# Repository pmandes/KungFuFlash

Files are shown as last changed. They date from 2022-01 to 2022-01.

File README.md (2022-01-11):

# Kung Fu Flash - Long PCB version

This version of the cartridge was developed for the following purposes:
- to fit into standard housings matching PCBs in format and size of the EasyFlash 3 cartridge
- to make SMD manual soldering easier
- to prevent the leverage effect when pressing the buttons from above, which stressed the cartridge connector and caused the C64 to crash.

The original design can be found [here](https://github.com/KimJorgensen/KungFuFlash).

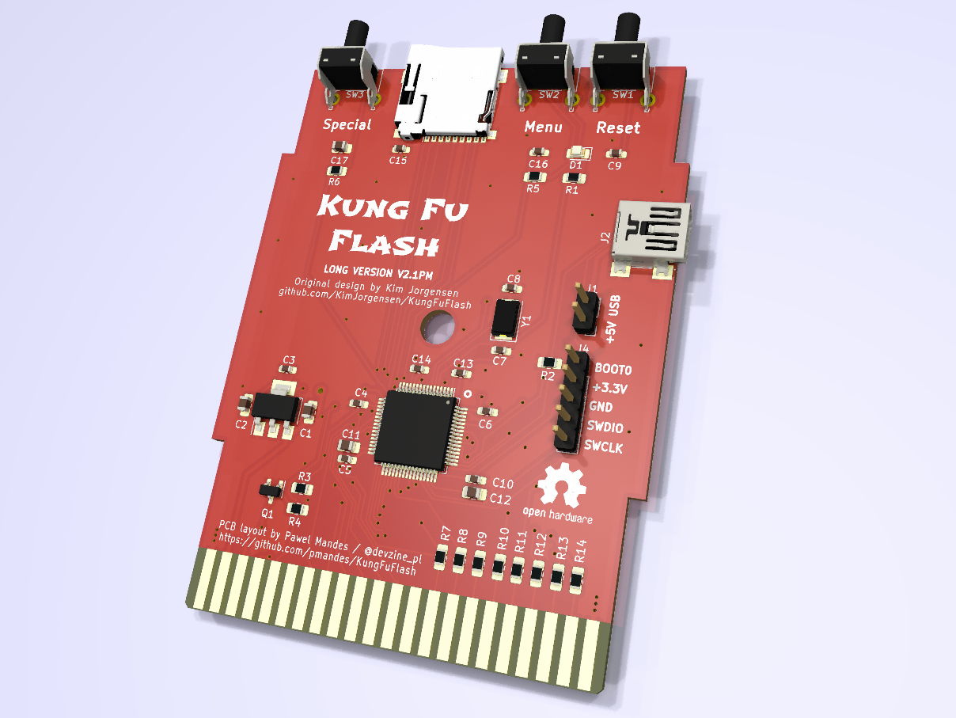
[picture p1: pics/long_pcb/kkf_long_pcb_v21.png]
KKF long board


Main changes:
- project migrated to KiCad 6.0
- 3D models for all components
- long PCB to fit common housings
- right angle tactile switches
- more durable Mini USB B socket for data transfer (you can use the same cable as EF3)
- 100Ω 0805 resistors for easier manual soldering (instead of resitor arrays)

The gerber files:
[KungFuFlash-Long-v2.1-PM.zip](https://github.com/pmandes/KungFuFlash/blob/long-board-cart/hardware/gerber/KungFuFlash-Long-v2.1-PM.zip)

Compatible housings:
- [KM-20B](https://www.tme.eu/en/details/km-20b/multipurpose-enclosures/maszczyk/)
- [Z7](https://www.kradex.eu/product/enclosures_two_part/z7_ps?lang=en)
- [Thingiverse](https://www.thingiverse.com/thing:1702546)
- "Commodore" type and others that EF3 fits

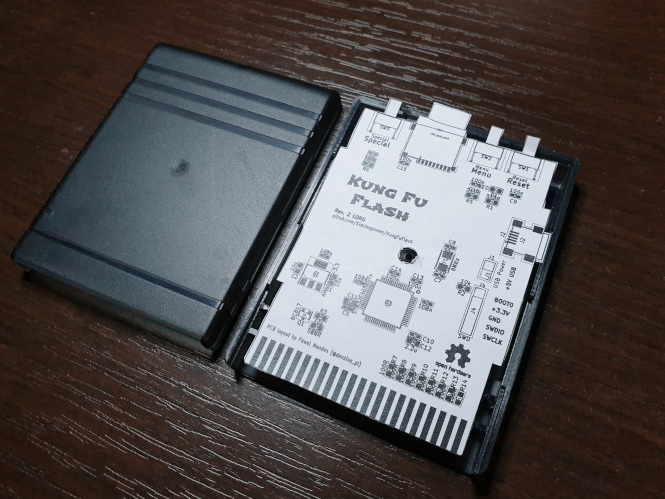
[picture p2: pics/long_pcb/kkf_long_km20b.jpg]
KKF KM-20B

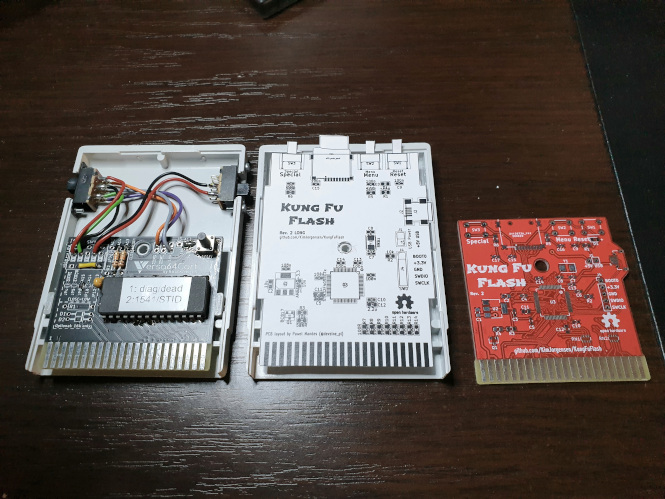
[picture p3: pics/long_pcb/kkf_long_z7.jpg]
KKF Z7

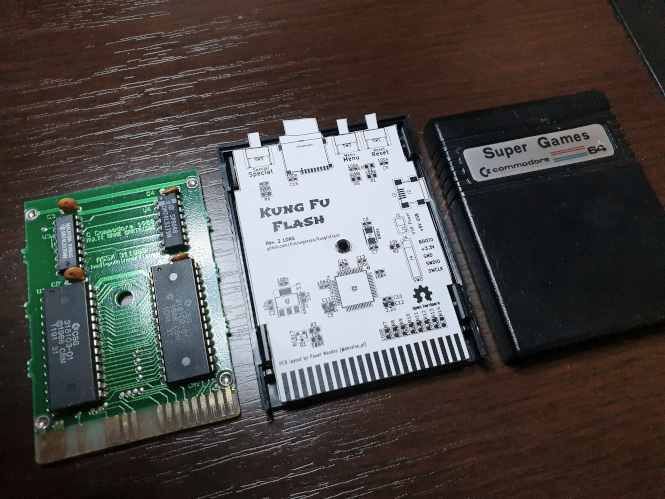
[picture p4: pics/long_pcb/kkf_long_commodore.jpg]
KKF Commodore Cart


# Kung Fu Flash
Cartridge for the Commodore 64 that packs a punch.

Kung Fu Flash Launcher

Kung Fu Flash can emulate different cartridge types, load PRG files and use D64 disk images.
Just place your desired CRT, PRG or D64 files on a FAT formatted microSD card and use the built-in launcher to execute them.

## Hardware
There are three buttons on the cartridge; a reset button, a menu button for starting the launcher, and a special button that is used by the freezer cartridges.

Cartridge Case

The PCB will fit the Stumpy Cartridge Case from TFW8b, you just need to drill some holes for the buttons and make a cut for the microSD card.
If you have mounted the USB connector you will need to cut a hole for that as well.

You can also 3D print a cartridge case as the one designed by bigby, [see here](https://www.thingiverse.com/thing:4153414).

Kung Fu Flash PCB

The gerber files and BOM can be found [here](https://github.com/KimJorgensen/KungFuFlash/releases/tag/rev.2).

## Supported Cartridges
The following cartridge types are currently supported:

* Normal cartridge (8k, 16k, Ultimax)
* Action Replay v4.x/v5/v6
* KCS Power Cartridge
* Final Cartridge III(+)
* Simons' BASIC
* Fun Play, Power Play
* Super Games
* Ocean type 1
* Epyx Fastload
* C64 Game System, System 3
* WarpSpeed
* Dinamic
* Zaxxon, Super Zaxxon
* Magic Desk, Domark, HES Australia
* Super Snapshot v5
* Comal-80
* EasyFlash
* Prophet64
* Freeze Frame
* Freeze Machine
* RGCD, Hucky
* Drean
* C128 Normal Cartridge (external function ROM)

## Supported File Types
The following file types are currently supported:

* Cartridge (CRT)
* C128 cartridge (ROM, BIN)
* Disk image (D64, D71, D81)
* Tape image (T64)
* Program (PRG, P00)
* Firmware update (UPD)

## USB Port
The USB port is active while the launcher is running allowing programs to be transferred from a PC using the EasyFlash 3 USB protocol.
Kung Fu Flash shows up as a standard serial port when connected to a PC not requiring any custom drivers to be installed.
This means, however, that the program on the PC side must be modified to support Kung Fu Flash.
For that reason a modified version of [EasyFlash 3 USB Utilities](3rd_party/ef3utils) and [EasyFlash 3 BBS](3rd_party/ef3bbs) has been included in this repository.

## Firmware Update
Just place the KungFuFlash_v1.xx.upd file on the SD card and select the file in the launcher to initiate the firmware update.
The newest firmware can be found [here](https://github.com/KimJorgensen/KungFuFlash/releases/).

For initial firmware installation, [see here](firmware/README.md).

## Limitations
Kung Fu Flash is a so called Software Defined Cartridge where a fast microcontroller emulates cartridge hardware in software.
This makes it extremely flexible, allowing different cartridge types to be supported at a relative low cost.

However, it can be challenging to get the C64 bus timing correct in software and in some places the timing is very close to the limit.
Even though Kung Fu Flash has been tested on different models of the Commodore 64, there is a chance that it doesn't work correctly on your specific model.
Use it at your own risk!

Kung Fu Flash will work with the PAL version of the Commodore 64 or Commodore 128. Support for the NTSC version is still considered experimental.

Disk drive emulation is using kernal vectors and will not work with fast loaders or software that uses direct hardware access which a lot of games does. Currently REL files are not supported and there is only limited write support.

## Thanks
Kung Fu Flash was based on or uses other open source projects:

* [EasyFlash 3](https://bitbucket.org/skoe/easyflash) by Thomas Giesel
* [Draco Browser](https://csdb.dk/release/?id=89910) by Sascha Bader
* [fatfs-stm32](https://github.com/colosimo/fatfs-stm32) by Aurelio Colosimo
* [FatFs](http://elm-chan.org/fsw/ff/00index_e.html) by ChaN
* [libusb_stm32](https://github.com/dmitrystu/libusb_stm32) by Dmitry Filimonchuk
* [stm32f4-bare-metal](https://github.com/fcayci/stm32f4-bare-metal) by Furkan Cayci
* [OpenC64Cart](https://github.com/SukkoPera/OpenC64Cart) by Giorgioggì
* [EasyFlash 3 USB Utilities](https://csdb.dk/release/?id=150097) by Tomaz Kac
* [Disk2easyflash](https://csdb.dk/release/?id=150323) by ALeX Kazik

and a few others. Please check the individual files for their license.

Thanks to Bjørn N. Jørgensen for giving this project its name.

Special thanks to the author of [Sidekick64](https://github.com/frntc/Sidekick64) Carsten Dachsbacher for his support and inspiration.

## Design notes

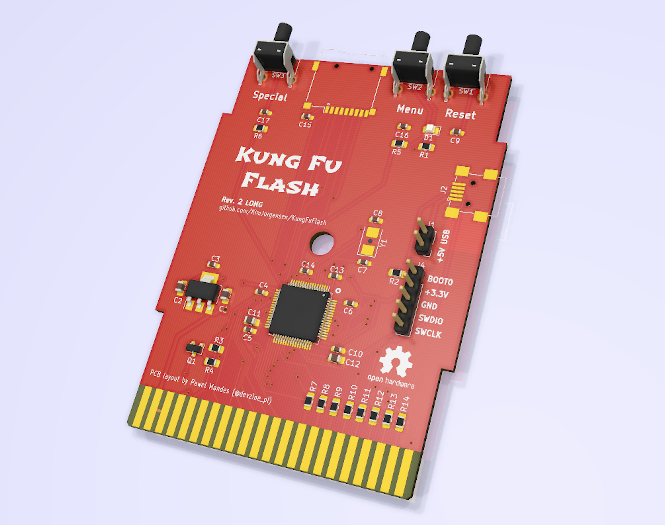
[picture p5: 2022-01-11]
pics/long_pcb/kkf_long_pcb_v1.png

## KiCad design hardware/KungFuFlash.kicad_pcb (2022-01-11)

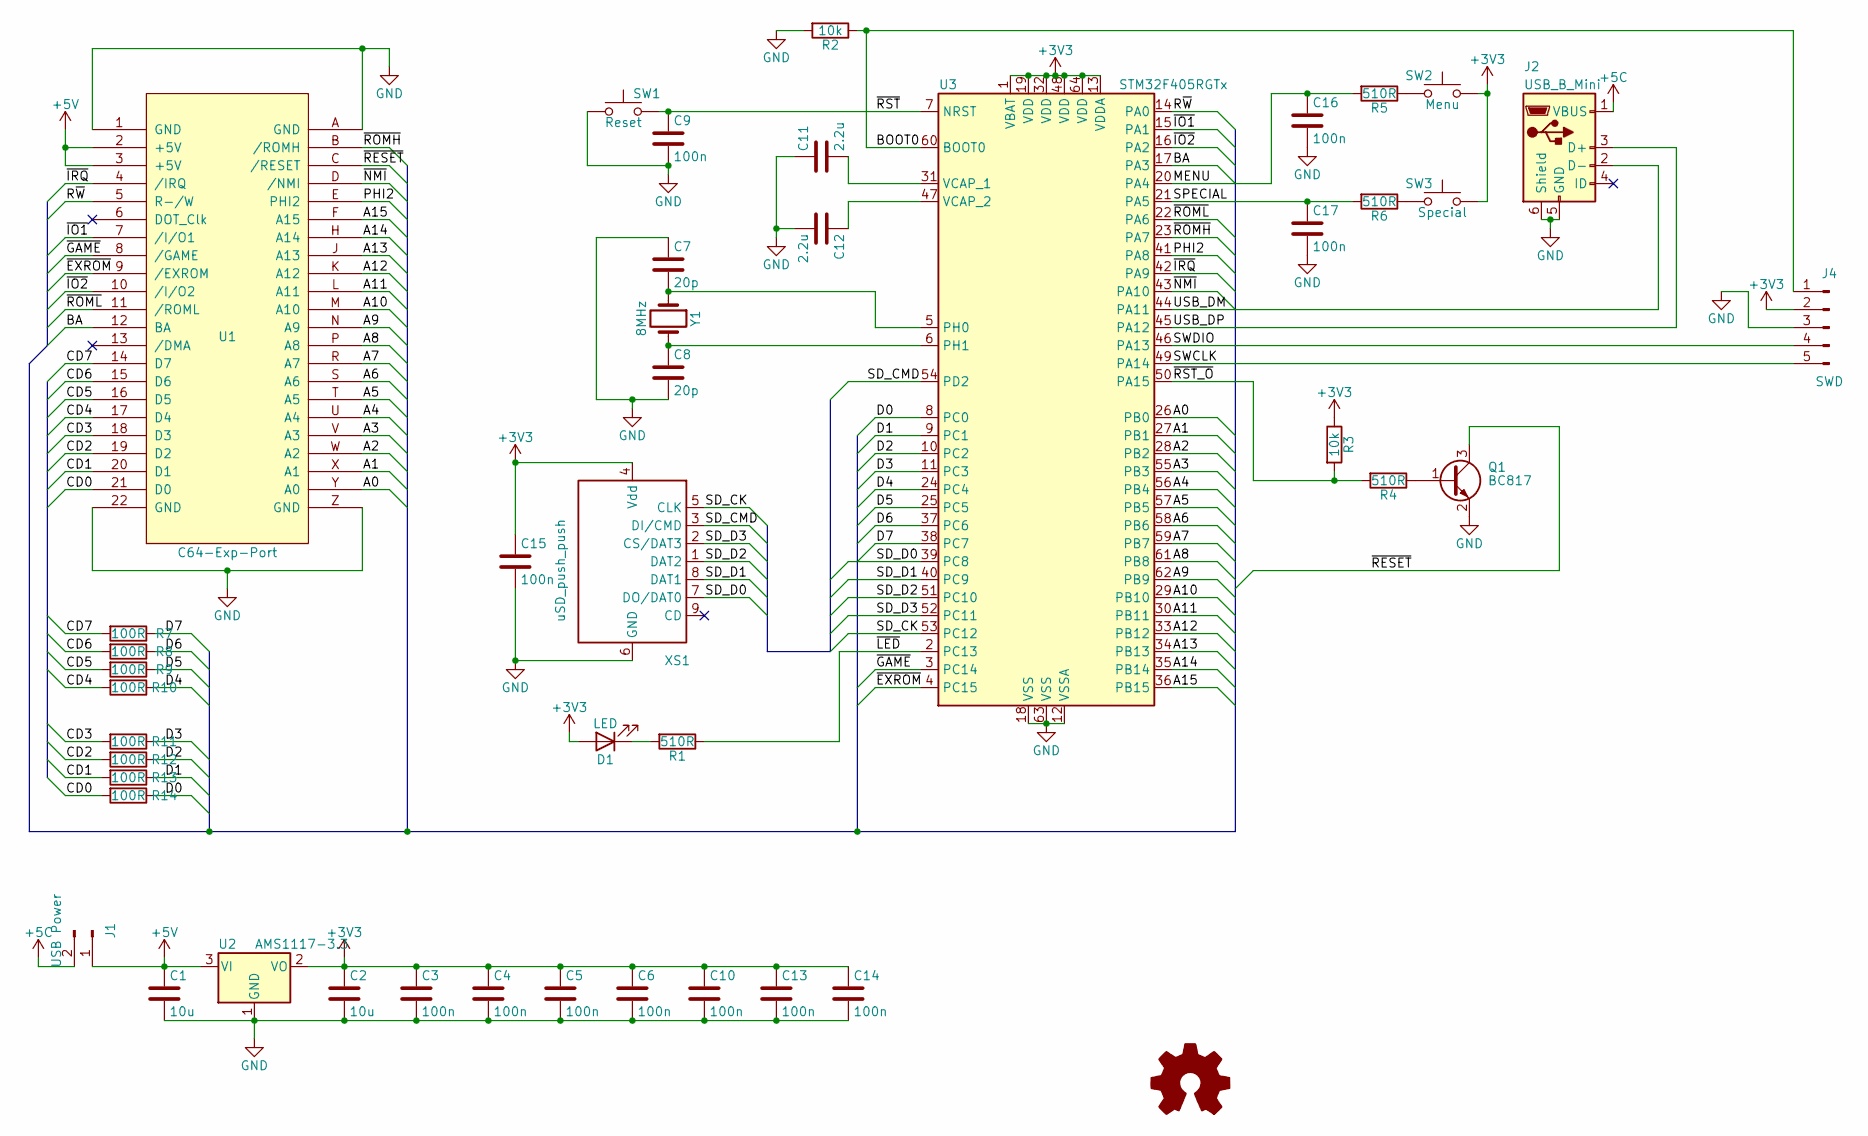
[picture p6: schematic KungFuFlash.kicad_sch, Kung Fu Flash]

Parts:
C1, C2: 10u; C_0805_2012Metric_Pad1.18x1.45mm_HandSolder
C3, C4, C5, C6, C9, C10, C13, C14, C15, C16: 100n; C_0603_1608Metric_Pad1.08x0.95mm_HandSolder
C7, C8: 20p; C_0603_1608Metric_Pad1.08x0.95mm_HandSolder
C11, C12: 2.2u; C_0805_2012Metric_Pad1.18x1.45mm_HandSolder
C17: 100n; C_0805_2012Metric_Pad1.18x1.45mm_HandSolder
D1: LED; LED_0805_2012Metric_Pad1.15x1.40mm_HandSolder
J1: USB Power; PinHeader_1x02_P2.54mm_Vertical
J2: USB_B_Mini; USB_Mini-B_Wuerth_65100516121_Horizontal
J4: SWD; PinHeader_1x05_P2.54mm_Vertical
Q1: BC817; SOT-23
R1, R4, R5, R6: 510R; R_0805_2012Metric_Pad1.20x1.40mm_HandSolder
R2, R3: 10k; R_0805_2012Metric_Pad1.20x1.40mm_HandSolder
R7, R8, R9, R10, R11, R12, R13, R14: 100R; R_0805_2012Metric_Pad1.20x1.40mm_HandSolder
SW1: Reset; SW_Tactile_SPST_Angled_PTS645Vx83-2LFS
SW2: Menu; SW_Tactile_SPST_Angled_PTS645Vx83-2LFS
SW3: Special; SW_Tactile_SPST_Angled_PTS645Vx83-2LFS
U1: C64-Exp-Port; C64-Cart
U2: AMS1117-3.3; SOT-223-3_TabPin2
U3: STM32F405RGTx; LQFP-64_10x10mm_P0.5mm
XS1: uSD_push_push; Conn_uSDcard
Y1: 8MHz; Crystal_SMD_5032-2Pin_5.0x3.2mm

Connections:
+3V3: C2.1, C3.1, C4.1, C5.1, C6.1, C10.1, C13.1, C14.1, C15.1, D1.2 (A), J4.2, R3.1, SW2.1, SW3.1, U2.2 (VO), U3.1 (VBAT), U3.13 (VDDA), U3.19 (VDD), U3.32 (VDD), U3.48 (VDD), U3.64 (VDD), XS1.4 (Vdd)
+5C: J1.2, J2.1 (VBUS)
+5V: C1.1, J1.1, U1.2 (+5V), U1.3 (+5V), U2.3 (VI)
/A0: U1.Y (A0), U3.26 (PB0)
/A1: U1.X (A1), U3.27 (PB1)
/A2: U1.W (A2), U3.28 (PB2)
/A3: U1.V (A3), U3.55 (PB3)
/A4: U1.U (A4), U3.56 (PB4)
/A5: U1.T (A5), U3.57 (PB5)
/A6: U1.S (A6), U3.58 (PB6)
/A7: U1.R (A7), U3.59 (PB7)
/A8: U1.P (A8), U3.61 (PB8)
/A9: U1.N (A9), U3.62 (PB9)
/A10: U1.M (A10), U3.29 (PB10)
/A11: U1.L (A11), U3.30 (PB11)
/A12: U1.K (A12), U3.33 (PB12)
/A13: U1.J (A13), U3.34 (PB13)
/A14: U1.H (A14), U3.35 (PB14)
/A15: U1.F (A15), U3.36 (PB15)
/BA: U1.12 (BA), U3.17 (PA3)
/BOOT0: J4.1, R2.1, U3.60 (BOOT0)
/CD0: R14.2, U1.21 (D0)
/CD1: R13.2, U1.20 (D1)
/CD2: R12.2, U1.19 (D2)
/CD3: R11.2, U1.18 (D3)
/CD4: R10.2, U1.17 (D4)
/CD5: R9.2, U1.16 (D5)
/CD6: R8.2, U1.15 (D6)
/CD7: R7.2, U1.14 (D7)
/D0: R14.1, U3.8 (PC0)
/D1: R13.1, U3.9 (PC1)
/D2: R12.1, U3.10 (PC2)
/D3: R11.1, U3.11 (PC3)
/D4: R10.1, U3.24 (PC4)
/D5: R9.1, U3.25 (PC5)
/D6: R8.1, U3.37 (PC6)
/D7: R7.1, U3.38 (PC7)
/MENU: C16.1, R5.2, U3.20 (PA4)
/PHI2: U1.E (PHI2), U3.41 (PA8)
/R~W: U1.5 (R-/W), U3.14 (PA0)
/SD_CK: U3.53 (PC12), XS1.5 (CLK)
/SD_CMD: U3.54 (PD2), XS1.3 (DI/CMD)
/SD_D0: U3.39 (PC8), XS1.7 (DO/DAT0)
/SD_D1: U3.40 (PC9), XS1.8 (DAT1)
/SD_D2: U3.51 (PC10), XS1.1 (DAT2)
/SD_D3: U3.52 (PC11), XS1.2 (CS/DAT3)
/SPECIAL: C17.1, R6.2, U3.21 (PA5)
/SWCLK: J4.5, U3.49 (PA14)
/SWDIO: J4.4, U3.46 (PA13)
/USB_DM: J2.2 (D-), U3.44 (PA11)
/USB_DP: J2.3 (D+), U3.45 (PA12)
/~EXROM: U1.9 (/EXROM), U3.4 (PC15)
/~GAME: U1.8 (/GAME), U3.3 (PC14)
/~IO1: U1.7 (/I/O1), U3.15 (PA1)
/~IO2: U1.10 (/I/O2), U3.16 (PA2)
/~IRQ: U1.4 (/IRQ), U3.42 (PA9)
/~LED: R1.1, U3.2 (PC13)
/~NMI: U1.D (/NMI), U3.43 (PA10)
/~RESET: Q1.3 (C), U1.C (/RESET)
/~ROMH: U1.B (/ROMH), U3.23 (PA7)
/~ROML: U1.11 (/ROML), U3.22 (PA6)
/~RST_O: R3.2, R4.2, U3.50 (PA15)
/~RST: C9.1, SW1.2, U3.7 (NRST)
GND: C1.2, C2.2, C3.2, C4.2, C5.2, C6.2, C7.1, C8.2, C9.2, C10.2, C11.1, C12.2, C13.2, C14.2, C15.2, C16.2, C17.2, J2.5 (GND), J2.6 (Shield), J4.3, Q1.2 (E), R2.2, SW1.1, U1.1 (GND), U1.22 (GND), U1.A (GND), U1.Z (GND), U2.1 (GND), U3.12 (VSSA), U3.18 (VSS), U3.63 (VSS), XS1.6 (GND)
unnamed: C7.2, U3.5 (PH0), Y1.1
unnamed: C8.1, U3.6 (PH1), Y1.2
unnamed: C11.2, U3.31 (VCAP_1)
unnamed: C12.1, U3.47 (VCAP_2)
unnamed: D1.1 (K), R1.2
unnamed: Q1.1 (B), R4.1
unnamed: R5.1, SW2.2
unnamed: R6.1, SW3.2

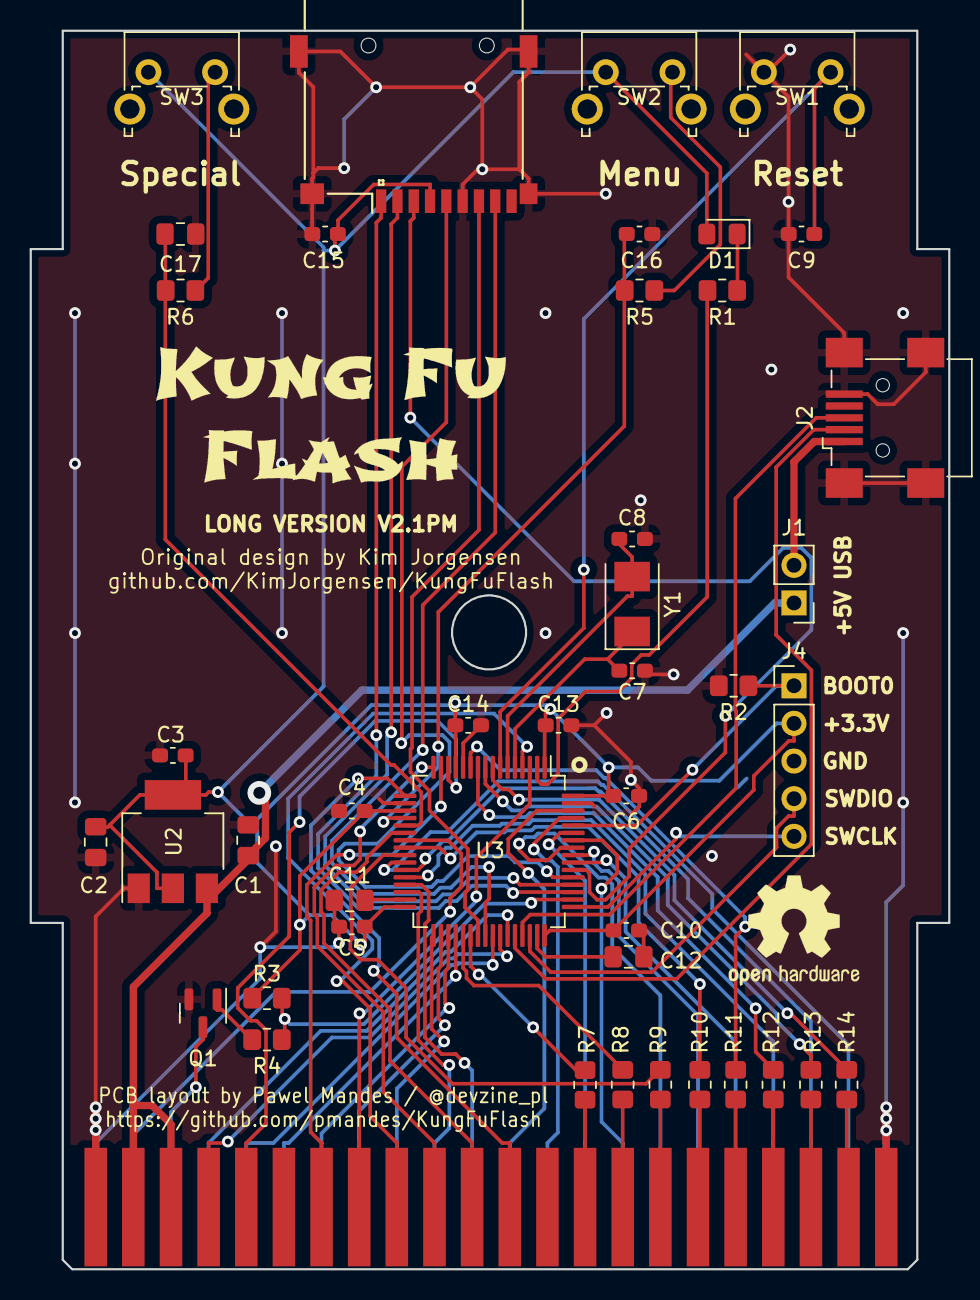
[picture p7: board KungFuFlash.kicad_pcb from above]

Board: 2 copper layers, 62.0 x 83.6 mm, 44 parts (0 on the bottom side), 72 nets.

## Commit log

2022-01-11 Long board cart PCB layout.
    [KungFuFlash.kicad_pcb, KungFuFlash.sch]
2022-01-11 Trace routing and layout cleanup.
    [KungFuFlash-notracks.kicad_pcb, KungFuFlash.kicad_pcb]
2022-01-11 New pics of the long PCB version.
2022-01-11 Tracks / vias optimization.
    [KungFuFlash.kicad_pcb]
2022-01-11 GND layers adjustments.
    [KungFuFlash.kicad_pcb]
2022-01-11 3D model and layers cleanup
    [KungFuFlash.kicad_pcb]
2022-01-11 Project migrated to KiCad 6.0
    [KungFuFlash-notracks.kicad_pcb, KungFuFlash.kicad_pcb, KungFuFlash.kicad_sch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]
